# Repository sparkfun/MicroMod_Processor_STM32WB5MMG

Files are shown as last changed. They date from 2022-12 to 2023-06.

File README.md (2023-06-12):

SparkFun MicroMod Processor Board - STM32WB5MMG 
========================================

MicroMod Processor Board - STM32WB5MMG (https://www.sparkfun.com/products/21438)

[*MicroMod Processor Board - STM32WB5MMG (DEV-21438)*](https://www.sparkfun.com/products/21438)

The MicroMod STM32WB5MMG Processor expands on SparkFun&apos;s MicroMod ST product line with a powerful combination of computing and wireless capabilities all on one Processor. The STM32WB5MMG from STMicroelectronics<sup>&trade;</sup> is an ultra-low power microcontroller that combines a pair of Arm<sup>&reg;</sup> Cortex<sup>&reg;</sup> processors; a Cortex-M4 processor for primary computing and a Cortex-M0 to run the 2.4 GHz radio. The radio is Bluetooth<sup>&reg;</sup> Low Energy 5.3, Zigbee<sup>&reg;</sup> 3.0, and OpenThread certified.

Repository Contents
-------------------

* **/Documentation** - Data sheets, additional product information
* **/Firmware** - Example code 
* **/Hardware** - Eagle design files (.brd, .sch)
* **/Production** - Production panel files (.brd)

Documentation
--------------
* **[Hookup Guide](https://learn.sparkfun.com/tutorials/micromod-stm32wb5mmg-hookup-guide)** - Basic hookup guide for the MicroMod Processor Board - STM32WB5MMG .
* **[SparkFun Fritzing repo](https://github.com/sparkfun/Fritzing_Parts)** - Fritzing diagrams for SparkFun products.
* **[SparkFun Graphical Datasheets](https://github.com/sparkfun/Graphical_Datasheets)** -Graphical Datasheets for various SparkFun products.

Product Versions
----------------
* [DEV-21438](https://www.sparkfun.com/products/21438)- MicroMod Processor for the STM32WB5MMG

License Information
-------------------

This product is _**open source**_! 

Please review the LICENSE.md file for license information. 

If you have any questions or concerns on licensing, please contact technical support on our [SparkFun forums](https://forum.sparkfun.com/viewforum.php?f=152).

Distributed as-is; no warranty is given.

- Your friends at SparkFun.

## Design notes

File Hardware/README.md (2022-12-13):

SparkFun <PRODUCT NAME> Design Files
=====================================

The .sch and .brd files hare are Eagle CAD schematic and PCB design files from SparkFun Electronics.
A freeware version of Autodesk Eagle can be found [here](https://www.autodesk.com/products/eagle/free-download).

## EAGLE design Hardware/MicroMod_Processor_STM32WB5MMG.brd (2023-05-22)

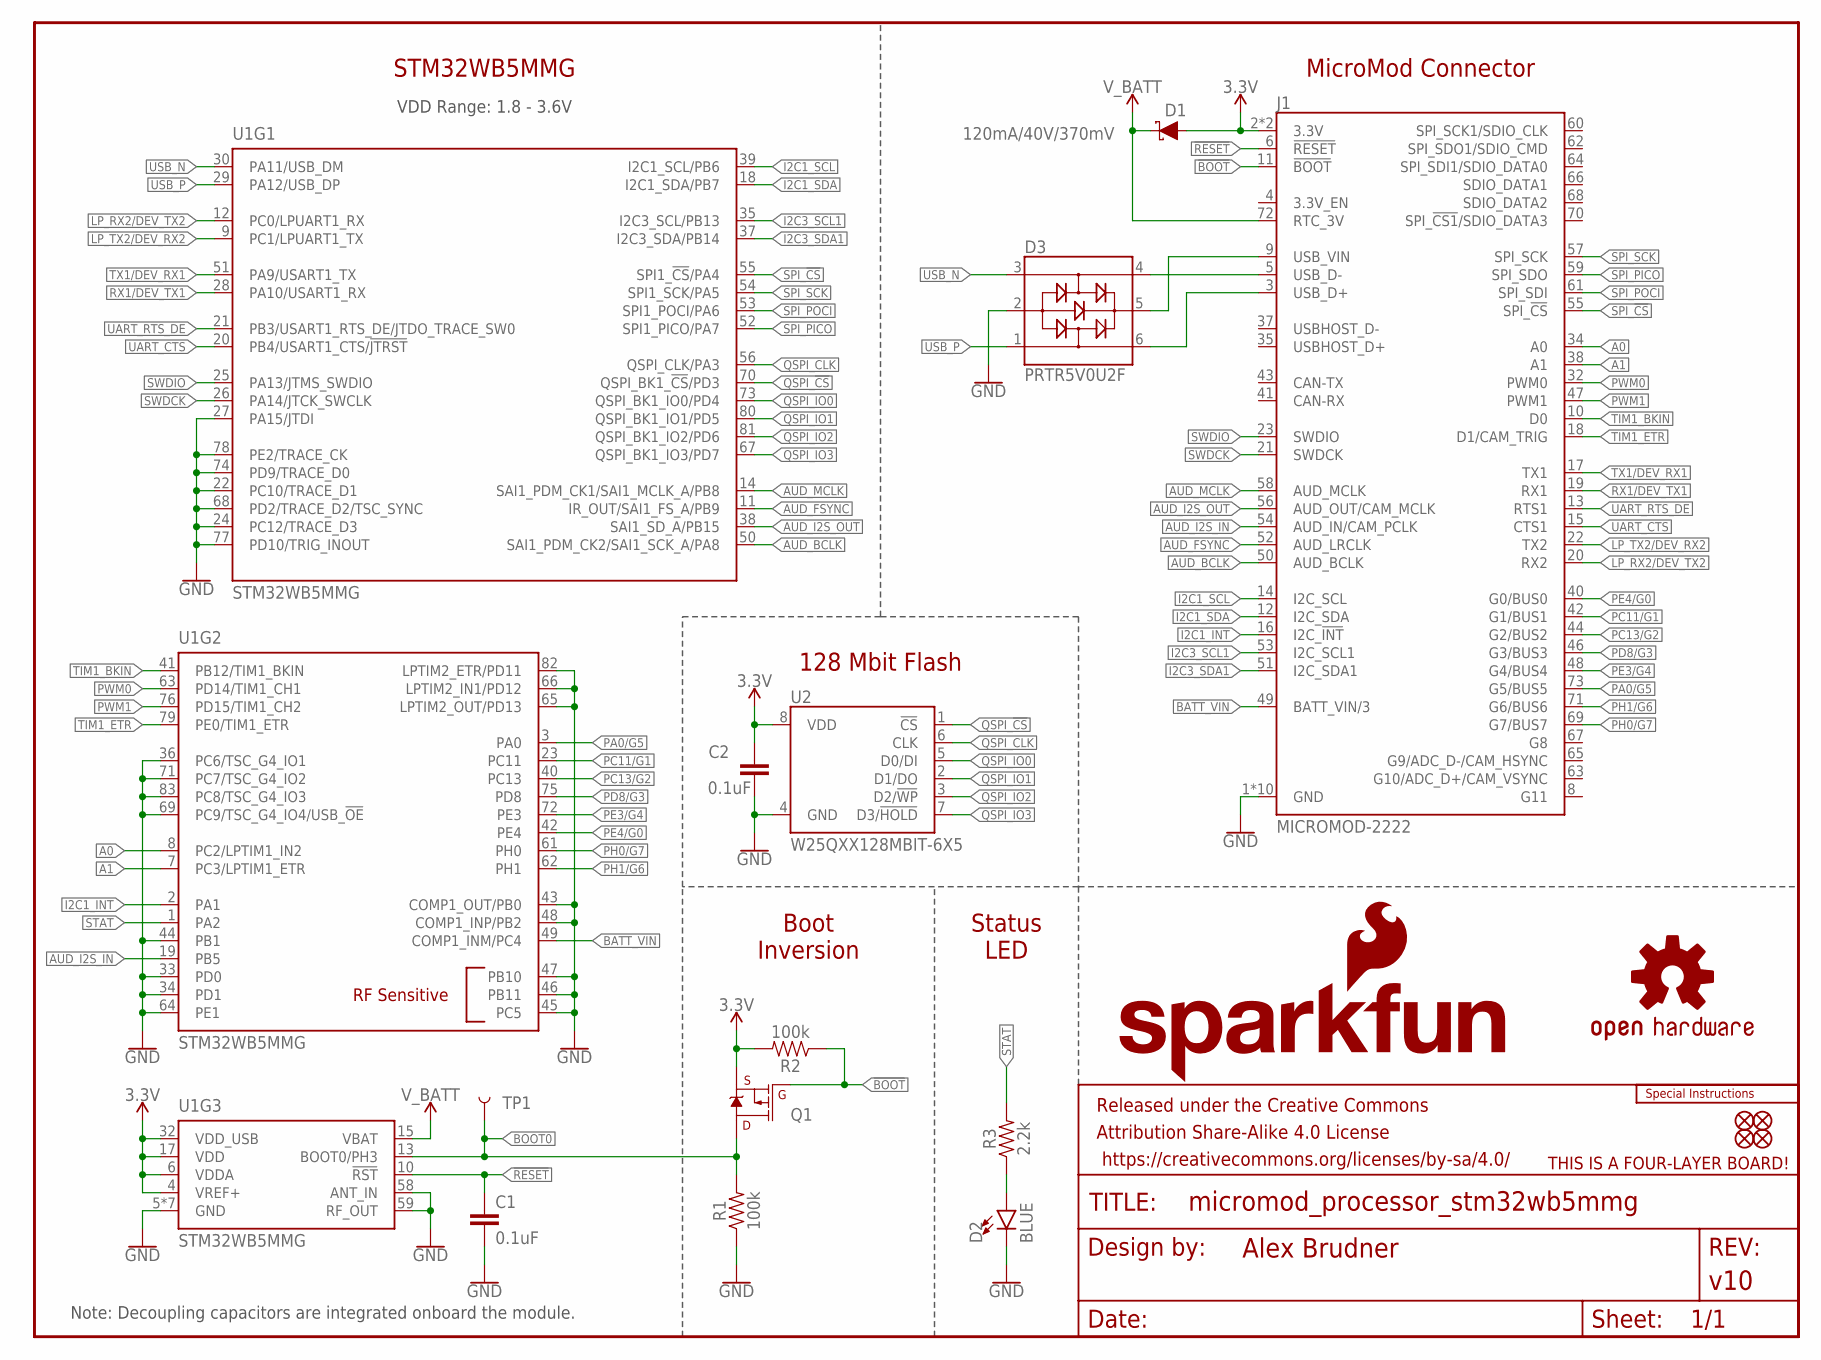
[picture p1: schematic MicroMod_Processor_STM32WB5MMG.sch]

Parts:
C1, C2: 0.1uF; 0402-TIGHT
D1: 120mA/40V/370mV; SOD-523
D2: BLUE; LED-0603
D3: PRTR5V0U2F; SOT886
FD1, FD2, FD3, FD4: FIDUCIALUFIDUCIAL; FIDUCIAL-MICRO
FRAME2: FRAME-LETTER; CREATIVE_COMMONS
J1: MICROMOD-2222; M.2-CARD-E-22
LOGO1: FOUR_LAYER_WARNING
LOGO2: OSHW-LOGOMINI; OSHW-LOGO-MINI
LOGO3: SFE_LOGO_NAME_FLAME.1_INCH; SFE_LOGO_NAME_FLAME_.1
LOGO4: SPECIAL_INSTRUCTIONS-ORDERING; ORDERING_INSTRUCTIONS
Q1: 20V/4.2A/52mΩ/1.4W; SOT23-3
R1, R2: 100k; 0402-TIGHT
R3: 2.2k; 0402-TIGHT
TP1: TEST-POINT3; PAD.03X.03
U1: STM32WB5MMG; SIP-LGA86
U2: W25QXX128MBIT-6X5; WSON-8-6X5

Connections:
3.3V: C2.1, D1.A, J1.2 (3.3V), J1.74 (3.3V), Q1.2 (S), R2.2, U1.4 (VREF+), U1.6 (VDDA), U1.17 (VDD), U1.32 (VDD_USB), U2.8 (VDD)
!BOOT!: J1.11 (!BOOT!), Q1.1 (G), R2.1
!RESET!: C1.1, J1.6 (!RESET!), U1.10 (!RST!)
A0: J1.34 (A0), U1.8 (PC2/LPTIM1_IN2)
A1: J1.38 (A1), U1.7 (PC3/LPTIM1_ETR)
AUD_BCLK: J1.50 (AUD_BCLK), U1.50 (SAI1_PDM_CK2/SAI1_SCK_A/PA8)
AUD_FSYNC: J1.52 (AUD_LRCLK), U1.11 (IR_OUT/SAI1_FS_A/PB9)
AUD_I2S_IN: J1.54 (AUD_IN/CAM_PCLK), U1.19 (PB5)
AUD_I2S_OUT: J1.56 (AUD_OUT/CAM_MCLK), U1.38 (SAI1_SD_A/PB15)
AUD_MCLK: J1.58 (AUD_MCLK), U1.14 (SAI1_PDM_CK1/SAI1_MCLK_A/PB8)
BATT_VIN: J1.49 (BATT_VIN/3), U1.49 (COMP1_INM/PC4)
BOOT0: Q1.3 (D), R1.2, TP1.1, U1.13 (BOOT0/PH3)
GND: C1.2, C2.2, D2.C, D3.2, J1.1 (GND), J1.7 (GND), J1.33 (GND), J1.36 (GND), J1.39 (GND), J1.45 (GND), J1.75 (GND), J1.GND1 (GND), J1.GND2 (GND), J1.GND3 (GND), R1.1, U1.5 (GND), U1.16 (GND), U1.22 (PC10/TRACE_D1), U1.24 (PC12/TRACE_D3), U1.27 (PA15/JTDI), U1.31 (GND), U1.33 (PD0), U1.34 (PD1), U1.36 (PC6/TSC_G4_IO1), U1.43 (COMP1_OUT/PB0), U1.44 (PB1), U1.45 (PC5), U1.46 (PB11), U1.47 (PB10), U1.48 (COMP1_INP/PB2), U1.57 (GND), U1.58 (ANT_IN), U1.59 (RF_OUT), U1.60 (GND), U1.64 (PE1), U1.65 (LPTIM2_OUT/PD13), U1.66 (LPTIM2_IN1/PD12), U1.68 (PD2/TRACE_D2/TSC_SYNC), U1.69 (PC9/TSC_G4_IO4/USB_!OE!), U1.71 (PC7/TSC_G4_IO2), U1.74 (PD9/TRACE_D0), U1.77 (PD10/TRIG_INOUT), U1.78 (PE2/TRACE_CK), U1.82 (LPTIM2_ETR/PD11), U1.83 (PC8/TSC_G4_IO3), U1.84 (GND), U1.86 (GND), U2.4 (GND)
I2C1_INT: J1.16 (I2C_!INT!), U1.2 (PA1)
I2C1_SCL: J1.14 (I2C_SCL), U1.39 (I2C1_SCL/PB6)
I2C1_SDA: J1.12 (I2C_SDA), U1.18 (I2C1_SDA/PB7)
I2C3_SCL1: J1.53 (I2C_SCL1), U1.35 (I2C3_SCL/PB13)
I2C3_SDA1: J1.51 (I2C_SDA1), U1.37 (I2C3_SDA/PB14)
LP_RX2/DEV_TX2: J1.20 (RX2), U1.12 (PC0/LPUART1_RX)
LP_TX2/DEV_RX2: J1.22 (TX2), U1.9 (PC1/LPUART1_TX)
unnamed: D2.A, R3.1
unnamed: D3.5, J1.9 (USB_VIN)
PA0/G5: J1.73 (G5/BUS5), U1.3 (PA0)
PC11/G1: J1.42 (G1/BUS1), U1.23 (PC11)
PC13/G2: J1.44 (G2/BUS2), U1.40 (PC13)
PD8/G3: J1.46 (G3/BUS3), U1.75 (PD8)
PE3/G4: J1.48 (G4/BUS4), U1.72 (PE3)
PE4/G0: J1.40 (G0/BUS0), U1.42 (PE4)
PH0/G7: J1.69 (G7/BUS7), U1.61 (PH0)
PH1/G6: J1.71 (G6/BUS6), U1.62 (PH1)
PWM0: J1.32 (PWM0), U1.63 (PD14/TIM1_CH1)
PWM1: J1.47 (PWM1), U1.76 (PD15/TIM1_CH2)
QSPI_!CS!: U1.70 (QSPI_BK1_!CS!/PD3), U2.1 (!CS!)
QSPI_CLK: U1.56 (QSPI_CLK/PA3), U2.6 (CLK)
QSPI_IO0: U1.73 (QSPI_BK1_IO0/PD4), U2.5 (D0/DI)
QSPI_IO1: U1.80 (QSPI_BK1_IO1/PD5), U2.2 (D1/DO)
QSPI_IO2: U1.81 (QSPI_BK1_IO2/PD6), U2.3 (D2/!WP!)
QSPI_IO3: U1.67 (QSPI_BK1_IO3/PD7), U2.7 (D3/!HOLD!)
RX1/DEV_TX1: J1.19 (RX1), U1.28 (PA10/USART1_RX)
SPI_!CS!: J1.55 (SPI_!CS!), U1.55 (SPI1_!CS!/PA4)
SPI_PICO: J1.59 (SPI_SDO), U1.52 (SPI1_PICO/PA7)
SPI_POCI: J1.61 (SPI_SDI), U1.53 (SPI1_POCI/PA6)
SPI_SCK: J1.57 (SPI_SCK), U1.54 (SPI1_SCK/PA5)
STAT: R3.2, U1.1 (PA2)
SWDCK: J1.21 (SWDCK), U1.26 (PA14/JTCK_SWCLK)
SWDIO: J1.23 (SWDIO), U1.25 (PA13/JTMS_SWDIO)
TIM1_BKIN: J1.10 (D0), U1.41 (PB12/TIM1_BKIN)
TIM1_ETR: J1.18 (D1/CAM_TRIG), U1.79 (PE0/TIM1_ETR)
TX1/DEV_RX1: J1.17 (TX1), U1.51 (PA9/USART1_TX)
UART_CTS: J1.15 (CTS1), U1.20 (PB4/USART1_CTS/!JTRST!)
UART_RTS_DE: J1.13 (RTS1), U1.21 (PB3/USART1_RTS_DE/JTDO_TRACE_SW0)
USBIN_N: D3.4, J1.5 (USB_D-)
USBIN_P: D3.6, J1.3 (USB_D+)
USB_N: D3.3, U1.30 (PA11/USB_DM)
USB_P: D3.1, U1.29 (PA12/USB_DP)
V_BATT: D1.C, J1.72 (RTC_3V), U1.15 (VBAT)

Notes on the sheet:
Note: Decoupling capacitors are integrated onboard the module.
VDD Range: 1.8 - 3.6V
STM32WB5MMG
MicroMod Connector
128 Mbit Flash
Boot Inversion
Status LED

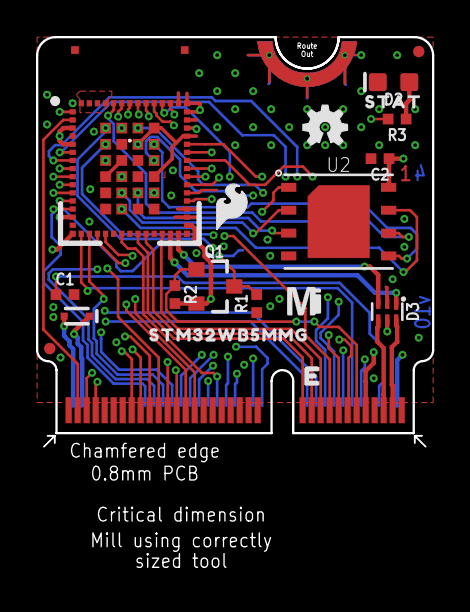
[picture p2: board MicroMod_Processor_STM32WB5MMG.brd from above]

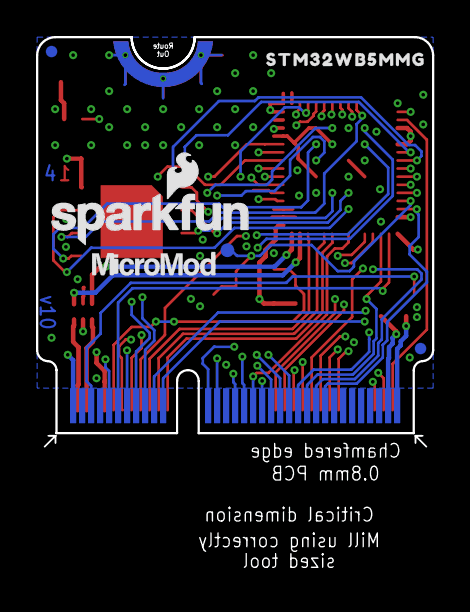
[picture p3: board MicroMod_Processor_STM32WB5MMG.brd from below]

Board: 4 copper layers, 22.0 x 22.8 mm, 29 parts (7 on the bottom side), 56 nets.

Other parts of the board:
U$1: MICROMOD_MI_LOGO_.35
U$2: MICROMOD_LOGO_.3
U$3: SFE_LOGO_FLAME_.1
U$4, U$5: STM32WB5MMG0
U$6: SFE_LOGO_FLAME_STOP_.1
U$7: STAT0

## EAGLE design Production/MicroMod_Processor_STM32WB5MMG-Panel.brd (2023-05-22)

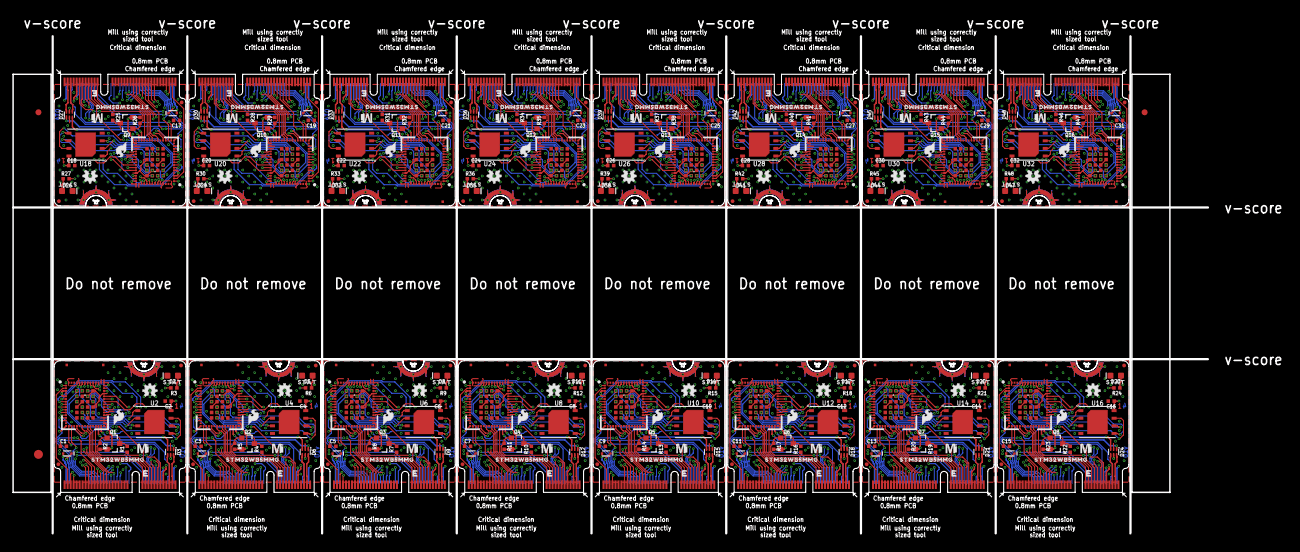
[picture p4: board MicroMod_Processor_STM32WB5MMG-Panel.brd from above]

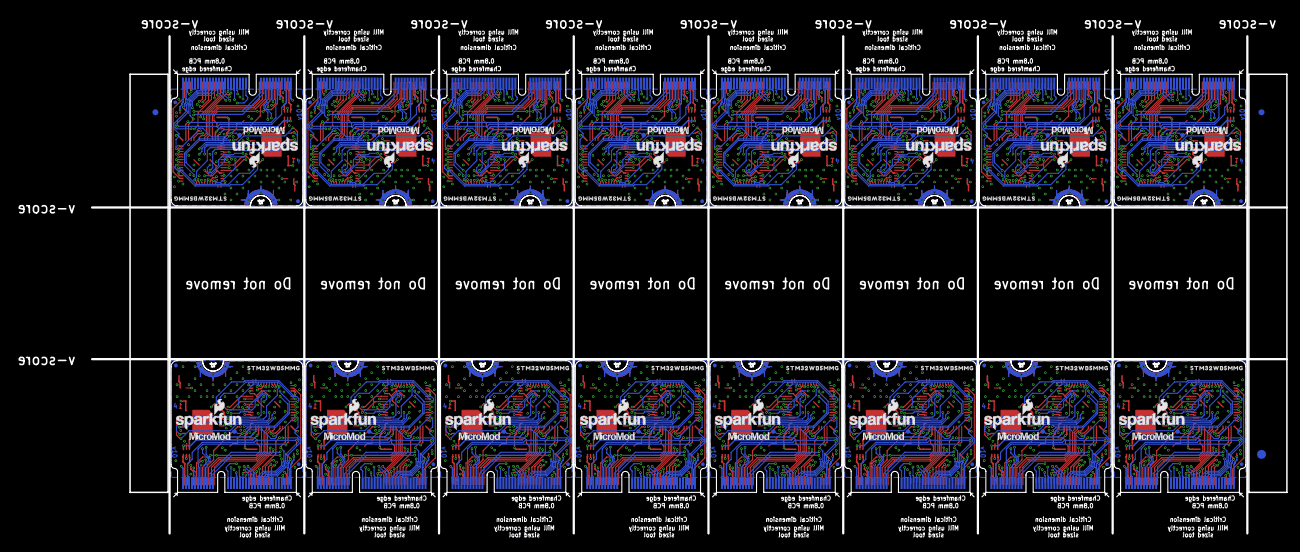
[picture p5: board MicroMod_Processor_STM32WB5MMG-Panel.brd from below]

Board: 4 copper layers, 199.6 x 83.1 mm, 438 parts (115 on the bottom side), 896 nets.

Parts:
C1, C2, C3, C4, C5, C6, C7, C8, C9, C10, C11, C12, C13, C14, C15, C16, C17, C18, C19, C20, C21, C22, C23, C24, C25, C26, C27, C28, C29, C30, C31, C32: 0.1uF; 0402-TIGHT
D1, D4, D7, D10, D13, D16, D19, D22, D25, D28, D31, D34, D37, D40, D43, D46: 120mA/40V/370mV; SOD-523
D2, D5, D8, D11, D14, D17, D20, D23, D26, D29, D32, D35, D38, D41, D44, D47: BLUE; LED-0603
D3, D6, D9, D12, D15, D18, D21, D24, D27, D30, D33, D36, D39, D42, D45, D48: PRTR5V0U2F; SOT886
E$1, E$2, E$3, E$4: FIDUCIAL-1X2
E$5, E$6: FIDUCIAL-1.5X3
FD1, FD2, FD3, FD4, FD5, FD6, FD7, FD8, FD9, FD10, FD11, FD12, FD13, FD14, FD15, FD16, FD17, FD18, FD19, FD20, FD21, FD22, FD23, FD24, FD25, FD26, FD27, FD28, FD29, FD30, FD31, FD32, FD33, FD34, FD35, FD36, FD37, FD38, FD39, FD40, FD41, FD42, FD43, FD44, FD45, FD46, FD47, FD48, FD49, FD50, FD51, FD52, FD53, FD54, FD55, FD56, FD57, FD58, FD59, FD60, FD61, FD62, FD63, FD64: FIDUCIALUFIDUCIAL; FIDUCIAL-MICRO
J1, J2, J3, J4, J5, J6, J7, J8, J9, J10, J11, J12, J13, J14, J15, J16: MICROMOD-2222; M.2-CARD-E-22
LOGO1, LOGO4, LOGO7, LOGO10, LOGO13, LOGO16, LOGO19, LOGO22, LOGO25, LOGO28, LOGO31, LOGO34, LOGO37, LOGO40, LOGO43, LOGO46: FOUR_LAYER_WARNING
LOGO2, LOGO5, LOGO8, LOGO11, LOGO14, LOGO17, LOGO20, LOGO23, LOGO26, LOGO29, LOGO32, LOGO35, LOGO38, LOGO41, LOGO44, LOGO47: OSHW-LOGOMINI; OSHW-LOGO-MINI
LOGO3, LOGO6, LOGO9, LOGO12, LOGO15, LOGO18, LOGO21, LOGO24, LOGO27, LOGO30, LOGO33, LOGO36, LOGO39, LOGO42, LOGO45, LOGO48: SFE_LOGO_NAME_FLAME.1_INCH; SFE_LOGO_NAME_FLAME_.1
Q1, Q2, Q3, Q4, Q5, Q6, Q7, Q8, Q9, Q10, Q11, Q12, Q13, Q14, Q15, Q16: 20V/4.2A/52mΩ/1.4W; SOT23-3
R1, R2, R4, R5, R7, R8, R10, R11, R13, R14, R16, R17, R19, R20, R22, R23, R25, R26, R28, R29, R31, R32, R34, R35, R37, R38, R40, R41, R43, R44, R46, R47: 100k; 0402-TIGHT
R3, R6, R9, R12, R15, R18, R21, R24, R27, R30, R33, R36, R39, R42, R45, R48: 2.2k; 0402-TIGHT
TP1, TP2, TP3, TP4, TP5, TP6, TP7, TP8, TP9, TP10, TP11, TP12, TP13, TP14, TP15, TP16: TEST-POINT3; PAD.03X.03
U1, U3, U5, U7, U9, U11, U13, U15, U17, U19, U21, U23, U25, U27, U29, U31: STM32WB5MMG; SIP-LGA86
U2, U4, U6, U8, U10, U12, U14, U16, U18, U20, U22, U24, U26, U28, U30, U32: W25QXX128MBIT-6X5; WSON-8-6X5
U$1, U$8, U$15, U$22, U$29, U$36, U$43, U$50, U$57, U$64, U$71, U$78, U$85, U$92, U$99, U$106: MICROMOD_MI_LOGO_.35
U$2, U$9, U$16, U$23, U$30, U$37, U$44, U$51, U$58, U$65, U$72, U$79, U$86, U$93, U$100, U$107: MICROMOD_LOGO_.3
U$3, U$10, U$17, U$24, U$31, U$38, U$45, U$52, U$59, U$66, U$73, U$80, U$87, U$94, U$101, U$108: SFE_LOGO_FLAME_.1
U$4, U$5, U$11, U$12, U$18, U$19, U$25, U$26, U$32, U$33, U$39, U$40, U$46, U$47, U$53, U$54, U$60, U$61, U$67, U$68, U$74, U$75, U$81, U$82, U$88, U$89, U$95, U$96, U$102, U$103, U$109, U$110: STM32WB5MMG0
U$6, U$13, U$20, U$27, U$34, U$41, U$48, U$55, U$62, U$69, U$76, U$83, U$90, U$97, U$104, U$111: SFE_LOGO_FLAME_STOP_.1
U$7, U$14, U$21, U$28, U$35, U$42, U$49, U$56, U$63, U$70, U$77, U$84, U$91, U$98, U$105, U$112: STAT0

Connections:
3.3V: C2.1, D1.A, J1.2, J1.74, Q1.2, R2.2, U1.4, U1.6, U1.17, U1.32, U2.8
3.3V1: C4.1, D4.A, J2.2, J2.74, Q2.2, R5.2, U3.4, U3.6, U3.17, U3.32, U4.8
3.3V2: C6.1, D7.A, J3.2, J3.74, Q3.2, R8.2, U5.4, U5.6, U5.17, U5.32, U6.8
3.3V3: C8.1, D10.A, J4.2, J4.74, Q4.2, R11.2, U7.4, U7.6, U7.17, U7.32, U8.8
3.3V4: C10.1, D13.A, J5.2, J5.74, Q5.2, R14.2, U9.4, U9.6, U9.17, U9.32, U10.8
3.3V5: C12.1, D16.A, J6.2, J6.74, Q6.2, R17.2, U11.4, U11.6, U11.17, U11.32, U12.8
3.3V6: C14.1, D19.A, J7.2, J7.74, Q7.2, R20.2, U13.4, U13.6, U13.17, U13.32, U14.8
3.3V7: C16.1, D22.A, J8.2, J8.74, Q8.2, R23.2, U15.4, U15.6, U15.17, U15.32, U16.8
3.3V8: C18.1, D25.A, J9.2, J9.74, Q9.2, R26.2, U17.4, U17.6, U17.17, U17.32, U18.8
3.3V9: C20.1, D28.A, J10.2, J10.74, Q10.2, R29.2, U19.4, U19.6, U19.17, U19.32, U20.8
3.3V10: C22.1, D31.A, J11.2, J11.74, Q11.2, R32.2, U21.4, U21.6, U21.17, U21.32, U22.8
3.3V11: C24.1, D34.A, J12.2, J12.74, Q12.2, R35.2, U23.4, U23.6, U23.17, U23.32, U24.8
3.3V12: C26.1, D37.A, J13.2, J13.74, Q13.2, R38.2, U25.4, U25.6, U25.17, U25.32, U26.8
3.3V13: C28.1, D40.A, J14.2, J14.74, Q14.2, R41.2, U27.4, U27.6, U27.17, U27.32, U28.8
3.3V14: C30.1, D43.A, J15.2, J15.74, Q15.2, R44.2, U29.4, U29.6, U29.17, U29.32, U30.8
3.3V15: C32.1, D46.A, J16.2, J16.74, Q16.2, R47.2, U31.4, U31.6, U31.17, U31.32, U32.8
!BOOT!: J1.11, Q1.1, R2.1
!BOOT!1: J2.11, Q2.1, R5.1
!BOOT!2: J3.11, Q3.1, R8.1
!BOOT!3: J4.11, Q4.1, R11.1
!BOOT!4: J5.11, Q5.1, R14.1
!BOOT!5: J6.11, Q6.1, R17.1
!BOOT!6: J7.11, Q7.1, R20.1
!BOOT!7: J8.11, Q8.1, R23.1
!BOOT!8: J9.11, Q9.1, R26.1
!BOOT!9: J10.11, Q10.1, R29.1
!BOOT!10: J11.11, Q11.1, R32.1
!BOOT!11: J12.11, Q12.1, R35.1
!BOOT!12: J13.11, Q13.1, R38.1
!BOOT!13: J14.11, Q14.1, R41.1
!BOOT!14: J15.11, Q15.1, R44.1
!BOOT!15: J16.11, Q16.1, R47.1
!RESET!: C1.1, J1.6, U1.10
!RESET!1: C3.1, J2.6, U3.10
!RESET!2: C5.1, J3.6, U5.10
!RESET!3: C7.1, J4.6, U7.10
!RESET!4: C9.1, J5.6, U9.10
!RESET!5: C11.1, J6.6, U11.10
!RESET!6: C13.1, J7.6, U13.10
!RESET!7: C15.1, J8.6, U15.10
!RESET!8: C17.1, J9.6, U17.10
!RESET!9: C19.1, J10.6, U19.10
!RESET!10: C21.1, J11.6, U21.10
!RESET!11: C23.1, J12.6, U23.10
!RESET!12: C25.1, J13.6, U25.10
!RESET!13: C27.1, J14.6, U27.10
!RESET!14: C29.1, J15.6, U29.10
!RESET!15: C31.1, J16.6, U31.10
A0: J1.34, U1.8
A1: J1.38, U1.7
A2: J2.34, U3.8
A3: J2.38, U3.7
A4: J3.34, U5.8
A5: J3.38, U5.7
A6: J4.34, U7.8
A7: J4.38, U7.7
A8: J5.34, U9.8
A9: J5.38, U9.7
A10: J6.34, U11.8
A11: J6.38, U11.7
A12: J7.34, U13.8
A13: J7.38, U13.7
A14: J8.34, U15.8
A15: J8.38, U15.7
A16: J9.34, U17.8
A17: J9.38, U17.7
A18: J10.34, U19.8
A19: J10.38, U19.7
A20: J11.34, U21.8
A21: J11.38, U21.7
A22: J12.34, U23.8
A23: J12.38, U23.7
A24: J13.34, U25.8
A25: J13.38, U25.7
A26: J14.34, U27.8
A27: J14.38, U27.7
A28: J15.34, U29.8
A29: J15.38, U29.7
A30: J16.34, U31.8
A31: J16.38, U31.7
AUD_BCLK: J1.50, U1.50
AUD_BCLK1: J2.50, U3.50
AUD_BCLK2: J3.50, U5.50
AUD_BCLK3: J4.50, U7.50
AUD_BCLK4: J5.50, U9.50
AUD_BCLK5: J6.50, U11.50
AUD_BCLK6: J7.50, U13.50
AUD_BCLK7: J8.50, U15.50
AUD_BCLK8: J9.50, U17.50
AUD_BCLK9: J10.50, U19.50
AUD_BCLK10: J11.50, U21.50
AUD_BCLK11: J12.50, U23.50
AUD_BCLK12: J13.50, U25.50
AUD_BCLK13: J14.50, U27.50
AUD_BCLK14: J15.50, U29.50
AUD_BCLK15: J16.50, U31.50
AUD_FSYNC: J1.52, U1.11
AUD_FSYNC1: J2.52, U3.11
AUD_FSYNC2: J3.52, U5.11
AUD_FSYNC3: J4.52, U7.11
AUD_FSYNC4: J5.52, U9.11
AUD_FSYNC5: J6.52, U11.11
AUD_FSYNC6: J7.52, U13.11
AUD_FSYNC7: J8.52, U15.11
AUD_FSYNC8: J9.52, U17.11
AUD_FSYNC9: J10.52, U19.11
AUD_FSYNC10: J11.52, U21.11
AUD_FSYNC11: J12.52, U23.11
AUD_FSYNC12: J13.52, U25.11
AUD_FSYNC13: J14.52, U27.11
AUD_FSYNC14: J15.52, U29.11
AUD_FSYNC15: J16.52, U31.11
AUD_I2S_IN: J1.54, U1.19
AUD_I2S_IN1: J2.54, U3.19
AUD_I2S_IN2: J3.54, U5.19
AUD_I2S_IN3: J4.54, U7.19
AUD_I2S_IN4: J5.54, U9.19
AUD_I2S_IN5: J6.54, U11.19
AUD_I2S_IN6: J7.54, U13.19
AUD_I2S_IN7: J8.54, U15.19
AUD_I2S_IN8: J9.54, U17.19
AUD_I2S_IN9: J10.54, U19.19
AUD_I2S_IN10: J11.54, U21.19
AUD_I2S_IN11: J12.54, U23.19
AUD_I2S_IN12: J13.54, U25.19
AUD_I2S_IN13: J14.54, U27.19
AUD_I2S_IN14: J15.54, U29.19
AUD_I2S_IN15: J16.54, U31.19
AUD_I2S_OUT: J1.56, U1.38
AUD_I2S_OUT1: J2.56, U3.38
AUD_I2S_OUT2: J3.56, U5.38
AUD_I2S_OUT3: J4.56, U7.38
AUD_I2S_OUT4: J5.56, U9.38
AUD_I2S_OUT5: J6.56, U11.38
AUD_I2S_OUT6: J7.56, U13.38
AUD_I2S_OUT7: J8.56, U15.38
AUD_I2S_OUT8: J9.56, U17.38
AUD_I2S_OUT9: J10.56, U19.38
AUD_I2S_OUT10: J11.56, U21.38
AUD_I2S_OUT11: J12.56, U23.38
AUD_I2S_OUT12: J13.56, U25.38
AUD_I2S_OUT13: J14.56, U27.38
AUD_I2S_OUT14: J15.56, U29.38
AUD_I2S_OUT15: J16.56, U31.38
AUD_MCLK: J1.58, U1.14
AUD_MCLK1: J2.58, U3.14
AUD_MCLK2: J3.58, U5.14
AUD_MCLK3: J4.58, U7.14
AUD_MCLK4: J5.58, U9.14
AUD_MCLK5: J6.58, U11.14
AUD_MCLK6: J7.58, U13.14
AUD_MCLK7: J8.58, U15.14
AUD_MCLK8: J9.58, U17.14
AUD_MCLK9: J10.58, U19.14
AUD_MCLK10: J11.58, U21.14
AUD_MCLK11: J12.58, U23.14
AUD_MCLK12: J13.58, U25.14
AUD_MCLK13: J14.58, U27.14
AUD_MCLK14: J15.58, U29.14
AUD_MCLK15: J16.58, U31.14
BATT_VIN: J1.49, U1.49
BATT_VIN1: J2.49, U3.49
BATT_VIN2: J3.49, U5.49
BATT_VIN3: J4.49, U7.49
BATT_VIN4: J5.49, U9.49
BATT_VIN5: J6.49, U11.49
BATT_VIN6: J7.49, U13.49
BATT_VIN7: J8.49, U15.49
BATT_VIN8: J9.49, U17.49
BATT_VIN9: J10.49, U19.49
BATT_VIN10: J11.49, U21.49
BATT_VIN11: J12.49, U23.49
BATT_VIN12: J13.49, U25.49
BATT_VIN13: J14.49, U27.49
BATT_VIN14: J15.49, U29.49
BATT_VIN15: J16.49, U31.49
BOOT0: Q1.3, R1.2, TP1.1, U1.13
BOOT1: Q2.3, R4.2, TP2.1, U3.13
BOOT2: Q3.3, R7.2, TP3.1, U5.13
BOOT3: Q4.3, R10.2, TP4.1, U7.13
BOOT4: Q5.3, R13.2, TP5.1, U9.13
BOOT5: Q6.3, R16.2, TP6.1, U11.13
BOOT6: Q7.3, R19.2, TP7.1, U13.13
BOOT7: Q8.3, R22.2, TP8.1, U15.13
BOOT8: Q9.3, R25.2, TP9.1, U17.13
BOOT9: Q10.3, R28.2, TP10.1, U19.13
BOOT10: Q11.3, R31.2, TP11.1, U21.13
BOOT11: Q12.3, R34.2, TP12.1, U23.13
BOOT12: Q13.3, R37.2, TP13.1, U25.13
BOOT13: Q14.3, R40.2, TP14.1, U27.13
BOOT14: Q15.3, R43.2, TP15.1, U29.13
BOOT15: Q16.3, R46.2, TP16.1, U31.13
GND: C1.2, C2.2, D2.C, D3.2, J1.1, J1.7, J1.33, J1.36, J1.39, J1.45, J1.75, J1.GND1, J1.GND2, J1.GND3, R1.1, U1.5, U1.16, U1.22, U1.24, U1.27, U1.31, U1.33, U1.34, U1.36, U1.43, U1.44, U1.45, U1.46, U1.47, U1.48, U1.57, U1.58, U1.59, U1.60, U1.64, U1.65, U1.66, U1.68, U1.69, U1.71, U1.74, U1.77, U1.78, U1.82, U1.83, U1.84, U1.86, U2.4
GND2: C3.2, C4.2, D5.C, D6.2, J2.1, J2.7, J2.33, J2.36, J2.39, J2.45, J2.75, J2.GND1, J2.GND2, J2.GND3, R4.1, U3.5, U3.16, U3.22, U3.24, U3.27, U3.31, U3.33, U3.34, U3.36, U3.43, U3.44, U3.45, U3.46, U3.47, U3.48, U3.57, U3.58, U3.59, U3.60, U3.64, U3.65, U3.66, U3.68, U3.69, U3.71, U3.74, U3.77, U3.78, U3.82, U3.83, U3.84, U3.86, U4.4
GND4: C5.2, C6.2, D8.C, D9.2, J3.1, J3.7, J3.33, J3.36, J3.39, J3.45, J3.75, J3.GND1, J3.GND2, J3.GND3, R7.1, U5.5, U5.16, U5.22, U5.24, U5.27, U5.31, U5.33, U5.34, U5.36, U5.43, U5.44, U5.45, U5.46, U5.47, U5.48, U5.57, U5.58, U5.59, U5.60, U5.64, U5.65, U5.66, U5.68, U5.69, U5.71, U5.74, U5.77, U5.78, U5.82, U5.83, U5.84, U5.86, U6.4
GND6: C7.2, C8.2, D11.C, D12.2, J4.1, J4.7, J4.33, J4.36, J4.39, J4.45, J4.75, J4.GND1, J4.GND2, J4.GND3, R10.1, U7.5, U7.16, U7.22, U7.24, U7.27, U7.31, U7.33, U7.34, U7.36, U7.43, U7.44, U7.45, U7.46, U7.47, U7.48, U7.57, U7.58, U7.59, U7.60, U7.64, U7.65, U7.66, U7.68, U7.69, U7.71, U7.74, U7.77, U7.78, U7.82, U7.83, U7.84, U7.86, U8.4
GND8: C9.2, C10.2, D14.C, D15.2, J5.1, J5.7, J5.33, J5.36, J5.39, J5.45, J5.75, J5.GND1, J5.GND2, J5.GND3, R13.1, U9.5, U9.16, U9.22, U9.24, U9.27, U9.31, U9.33, U9.34, U9.36, U9.43, U9.44, U9.45, U9.46, U9.47, U9.48, U9.57, U9.58, U9.59, U9.60, U9.64, U9.65, U9.66, U9.68, U9.69, U9.71, U9.74, U9.77, U9.78, U9.82, U9.83, U9.84, U9.86, U10.4
GND10: C11.2, C12.2, D17.C, D18.2, J6.1, J6.7, J6.33, J6.36, J6.39, J6.45, J6.75, J6.GND1, J6.GND2, J6.GND3, R16.1, U11.5, U11.16, U11.22, U11.24, U11.27, U11.31, U11.33, U11.34, U11.36, U11.43, U11.44, U11.45, U11.46, U11.47, U11.48, U11.57, U11.58, U11.59, U11.60, U11.64, U11.65, U11.66, U11.68, U11.69, U11.71, U11.74, U11.77, U11.78, U11.82, U11.83, U11.84, U11.86, U12.4
GND12: C13.2, C14.2, D20.C, D21.2, J7.1, J7.7, J7.33, J7.36, J7.39, J7.45, J7.75, J7.GND1, J7.GND2, J7.GND3, R19.1, U13.5, U13.16, U13.22, U13.24, U13.27, U13.31, U13.33, U13.34, U13.36, U13.43, U13.44, U13.45, U13.46, U13.47, U13.48, U13.57, U13.58, U13.59, U13.60, U13.64, U13.65, U13.66, U13.68, U13.69, U13.71, U13.74, U13.77, U13.78, U13.82, U13.83, U13.84, U13.86, U14.4
GND14: C15.2, C16.2, D23.C, D24.2, J8.1, J8.7, J8.33, J8.36, J8.39, J8.45, J8.75, J8.GND1, J8.GND2, J8.GND3, R22.1, U15.5, U15.16, U15.22, U15.24, U15.27, U15.31, U15.33, U15.34, U15.36, U15.43, U15.44, U15.45, U15.46, U15.47, U15.48, U15.57, U15.58, U15.59, U15.60, U15.64, U15.65, U15.66, U15.68, U15.69, U15.71, U15.74, U15.77, U15.78, U15.82, U15.83, U15.84, U15.86, U16.4
GND16: C17.2, C18.2, D26.C, D27.2, J9.1, J9.7, J9.33, J9.36, J9.39, J9.45, J9.75, J9.GND1, J9.GND2, J9.GND3, R25.1, U17.5, U17.16, U17.22, U17.24, U17.27, U17.31, U17.33, U17.34, U17.36, U17.43, U17.44, U17.45, U17.46, U17.47, U17.48, U17.57, U17.58, U17.59, U17.60, U17.64, U17.65, U17.66, U17.68, U17.69, U17.71, U17.74, U17.77, U17.78, U17.82, U17.83, U17.84, U17.86, U18.4
GND18: C19.2, C20.2, D29.C, D30.2, J10.1, J10.7, J10.33, J10.36, J10.39, J10.45, J10.75, J10.GND1, J10.GND2, J10.GND3, R28.1, U19.5, U19.16, U19.22, U19.24, U19.27, U19.31, U19.33, U19.34, U19.36, U19.43, U19.44, U19.45, U19.46, U19.47, U19.48, U19.57, U19.58, U19.59, U19.60, U19.64, U19.65, U19.66, U19.68, U19.69, U19.71, U19.74, U19.77, U19.78, U19.82, U19.83, U19.84, U19.86, U20.4
GND20: C21.2, C22.2, D32.C, D33.2, J11.1, J11.7, J11.33, J11.36, J11.39, J11.45, J11.75, J11.GND1, J11.GND2, J11.GND3, R31.1, U21.5, U21.16, U21.22, U21.24, U21.27, U21.31, U21.33, U21.34, U21.36, U21.43, U21.44, U21.45, U21.46, U21.47, U21.48, U21.57, U21.58, U21.59, U21.60, U21.64, U21.65, U21.66, U21.68, U21.69, U21.71, U21.74, U21.77, U21.78, U21.82, U21.83, U21.84, U21.86, U22.4
GND22: C23.2, C24.2, D35.C, D36.2, J12.1, J12.7, J12.33, J12.36, J12.39, J12.45, J12.75, J12.GND1, J12.GND2, J12.GND3, R34.1, U23.5, U23.16, U23.22, U23.24, U23.27, U23.31, U23.33, U23.34, U23.36, U23.43, U23.44, U23.45, U23.46, U23.47, U23.48, U23.57, U23.58, U23.59, U23.60, U23.64, U23.65, U23.66, U23.68, U23.69, U23.71, U23.74, U23.77, U23.78, U23.82, U23.83, U23.84, U23.86, U24.4
GND24: C25.2, C26.2, D38.C, D39.2, J13.1, J13.7, J13.33, J13.36, J13.39, J13.45, J13.75, J13.GND1, J13.GND2, J13.GND3, R37.1, U25.5, U25.16, U25.22, U25.24, U25.27, U25.31, U25.33, U25.34, U25.36, U25.43, U25.44, U25.45, U25.46, U25.47, U25.48, U25.57, U25.58, U25.59, U25.60, U25.64, U25.65, U25.66, U25.68, U25.69, U25.71, U25.74, U25.77, U25.78, U25.82, U25.83, U25.84, U25.86, U26.4
GND26: C27.2, C28.2, D41.C, D42.2, J14.1, J14.7, J14.33, J14.36, J14.39, J14.45, J14.75, J14.GND1, J14.GND2, J14.GND3, R40.1, U27.5, U27.16, U27.22, U27.24, U27.27, U27.31, U27.33, U27.34, U27.36, U27.43, U27.44, U27.45, U27.46, U27.47, U27.48, U27.57, U27.58, U27.59, U27.60, U27.64, U27.65, U27.66, U27.68, U27.69, U27.71, U27.74, U27.77, U27.78, U27.82, U27.83, U27.84, U27.86, U28.4
GND28: C29.2, C30.2, D44.C, D45.2, J15.1, J15.7, J15.33, J15.36, J15.39, J15.45, J15.75, J15.GND1, J15.GND2, J15.GND3, R43.1, U29.5, U29.16, U29.22, U29.24, U29.27, U29.31, U29.33, U29.34, U29.36, U29.43, U29.44, U29.45, U29.46, U29.47, U29.48, U29.57, U29.58, U29.59, U29.60, U29.64, U29.65, U29.66, U29.68, U29.69, U29.71, U29.74, U29.77, U29.78, U29.82, U29.83, U29.84, U29.86, U30.4
GND30: C31.2, C32.2, D47.C, D48.2, J16.1, J16.7, J16.33, J16.36, J16.39, J16.45, J16.75, J16.GND1, J16.GND2, J16.GND3, R46.1, U31.5, U31.16, U31.22, U31.24, U31.27, U31.31, U31.33, U31.34, U31.36, U31.43, U31.44, U31.45, U31.46, U31.47, U31.48, U31.57, U31.58, U31.59, U31.60, U31.64, U31.65, U31.66, U31.68, U31.69, U31.71, U31.74, U31.77, U31.78, U31.82, U31.83, U31.84, U31.86, U32.4
I2C1_INT: J1.16, U1.2
I2C1_INT1: J2.16, U3.2
I2C1_INT2: J3.16, U5.2
I2C1_INT3: J4.16, U7.2
I2C1_INT4: J5.16, U9.2
I2C1_INT5: J6.16, U11.2
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

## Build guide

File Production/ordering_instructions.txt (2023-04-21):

panel size, 194x70mm
PCB thickness, 0.8mm
number of layers, 4
controlled impedance, JLC7628
bevel, Gold Fingers + 45° Finger Chamfered
material, TG155
soldermask color, Red
silkscreen color, White
oz copper, 1oz
finish, ENIG
stencils, top
pcs per panel, 16
min trace width, 0.1500mm / 0.0059in
min drill size, 0.2000mm / 0.0079in
filename to layer stackup 1/2/3/4: GTL, GL2, GL3, GBL

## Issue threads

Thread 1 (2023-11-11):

Cannot get basic examples working on the Asset Tracker board using the STM32WB5MMG processor.

peekd, 2023-11-11:
Trying to get AssetTracker_Example1_Blink going but can't even compile (see errors below).

From another user - dboddie - 👍

In file included from D:\code\Asset_Tracker\MicroMod_Asset_Tracker-main\Examples\AssetTracker_Example1_Blink\AssetTracker_Example1_Blink.ino:39:
D:\code\Asset_Tracker\MicroMod_Asset_Tracker-main\Examples\AssetTracker_Example1_Blink\AssetTrackerPins.h:90:24: error: 'RX1' was not declared in this scope
90 | HardwareSerial Serial1(RX1, TX1);
| ^~~
D:\code\Asset_Tracker\MicroMod_Asset_Tracker-main\Examples\AssetTracker_Example1_Blink\AssetTrackerPins.h:90:29: error: 'TX1' was not declared in this scope
90 | HardwareSerial Serial1(RX1, TX1);
| ^~~
D:\code\Asset_Tracker\MicroMod_Asset_Tracker-main\Examples\AssetTracker_Example1_Blink\AssetTrackerPins.h:105:28: error: 'G0' was not declared in this scope; did you mean 'y0'?
105 | const int MICROSD_CS = G0; // Output: Active low
| ^~
| y0
D:\code\Asset_Tracker\MicroMod_Asset_Tracker-main\Examples\AssetTracker_Example1_Blink\AssetTrackerPins.h:106:28: error: 'G1' was not declared in this scope; did you mean 'y1'?
106 | const int MICROSD_PWR_EN = G1; // Output: Pull low to enable power for the SD card. Pull high to disable.
| ^~
| y1
D:\code\Asset_Tracker\MicroMod_Asset_Tracker-main\Examples\AssetTracker_Example1_Blink\AssetTrackerPins.h:107:28: error: 'G2' was not declared in this scope; did you mean 'D2'?
107 | const int SARA_PWR = G2; // Output: Pull high then low to switch the SARA-R5 on. Pull high for five seconds then low again to switch it off.
| ^~
| D2
D:\code\Asset_Tracker\MicroMod_Asset_Tracker-main\Examples\AssetTracker_Example1_Blink\AssetTrackerPins.h:108:28: error: 'G3' was not declared in this scope; did you mean 'D3'?
108 | const int IMU_PWR_EN = G3; // Output: Pull high to enable power for the IMU. Pull low to disable.
| ^~
| D3
D:\code\Asset_Tracker\MicroMod_Asset_Tracker-main\Examples\AssetTracker_Example1_Blink\AssetTrackerPins.h:109:28: error: 'G4' was not declared in this scope; did you mean 'D4'?
109 | const int SARA_RI = G4; // Input: SARA-R5 Ring Indicator pin. Becomes CTS2 in 2-UART mode.
| ^~
| D4
D:\code\Asset_Tracker\MicroMod_Asset_Tracker-main\Examples\AssetTracker_Example1_Blink\AssetTrackerPins.h:110:28: error: 'G5' was not declared in this scope; did you mean 'D5'?
110 | const int SARA_INT = G5; // Input: SARA-R5 EXT_INT interrupt pin.
| ^~
| D5
D:\code\Asset_Tracker\MicroMod_Asset_Tracker-main\Examples\AssetTracker_Example1_Blink\AssetTrackerPins.h:111:28: error: 'G6' was not declared in this scope; did you mean 'D6'?
111 | const int SARA_ON = G6; // Input: Pulled low when the SARA-R5 is on. Pulled high when the SARA-R5 is off.
| ^~
| D6
D:\code\Asset_Tracker\MicroMod_Asset_Tracker-main\Examples\AssetTracker_Example1_Blink\AssetTrackerPins.h:87:16: error: 'INT' was not declared in this scope; did you mean 'IN'?
87 | #define I2CINT INT
| ^~~
D:\code\Asset_Tracker\MicroMod_Asset_Tracker-main\Examples\AssetTracker_Example1_Blink\AssetTrackerPins.h:121:21: note: in expansion of macro 'I2CINT'
121 | const int IMU_INT = I2CINT; // Input: IMU interrupt pin
| ^~~~~~

exit status 1

Compilation error: 'RX1' was not declared in this scope

SFE-Brudnerd, 2023-11-15:
Hi @peekd, I've got this on my to-do list, but I probably won't be able to get to it for a couple weeks due to higher priority work. In the meantime, please feel free to submit a pull request in the `Arduino_Core_STM32` repo and add me as a reviewer. It would be an easy first PR for you. Please note that whether I do it or you do it, you won't see the change in Arduino immediately as they only update for tags. In the meantime, you can clone the `Arduino_Core_STM32` repo to your `$Arduino\hardware` folder, and after restarting Arduino it should show up as `STM32 MCU based boards (in Sketchbook)` in your boards drop-down list and you can pick the board from there. Thanks!

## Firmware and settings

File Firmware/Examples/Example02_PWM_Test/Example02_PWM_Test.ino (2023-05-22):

/**
 * @file Example02_PWM_Test.ino
 * @brief This example sets the PWM channels to be read by an oscilloscope.
 * @copyright SPDX-License-Identifier: MIT
 * @author Alex Brudner, SparkFun Electronics
 * @date 2023-04-18
 * @note Based on the PWM example from ST here:
 * https://github.com/stm32duino/STM32Examples
 *
 * Feel like supporting open source hardware?
 * Buy a board from SparkFun!
 *      MicroMod STM32WB5MMG Processor Board
 *        | https://www.sparkfun.com/products/21438
 *      MicroMod ATP Carrier Board                       
 *        | https://www.sparkfun.com/products/16885
 */

#include <Arduino.h>

#define PWM0 PD14
#define PWM1 PD15
// #define EX_TRIG PE0
// #define PWM_BRK PB12

void setup() {
  // put your setup code here, to run once:
  Serial.begin(115200);
  while(!Serial) { delay(100); };

  Serial.println(F("Begin PWM Test."));


  TIM_TypeDef *tim_pwm0 = (TIM_TypeDef *)pinmap_peripheral(digitalPinToPinName(PWM0), PinMap_PWM);
  uint32_t channel_pwm0 = STM_PIN_CHANNEL(pinmap_function(digitalPinToPinName(PWM0), PinMap_PWM));
  
  HardwareTimer *MyTim_pwm0 = new HardwareTimer(tim_pwm0);
  MyTim_pwm0->setPWM(channel_pwm0, PWM0, 50000, 25);

  TIM_TypeDef *tim_pwm1 = (TIM_TypeDef *)pinmap_peripheral(digitalPinToPinName(PWM1), PinMap_PWM);
  uint32_t channel_pwm1 = STM_PIN_CHANNEL(pinmap_function(digitalPinToPinName(PWM1), PinMap_PWM));

  
  HardwareTimer *MyTim_pwm1 = new HardwareTimer(tim_pwm1);
  MyTim_pwm1->setPWM(channel_pwm1, PWM1, 50000, 75);  
}

void loop() {

}

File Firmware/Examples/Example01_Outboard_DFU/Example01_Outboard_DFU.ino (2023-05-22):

/**
 * @file Example01_Outboard_DFU.ino
 * @brief This example performs an Outboard Device Firmware Update.
 * @copyright SPDX-License-Identifier: MIT
 * @author Alex Brudner, SparkFun Electronics
 * @date 2023-04-13
 * @note Based on the DFU example from Blues Wireless. See
 * https://github.com/blues/note-outboard-dfu
 * 
 * ========== HARDWARE CONNECTIONS ==========
 * MicroMod STM32WB5MMG Processor Board => MicroMod Main Board => MicroMod 
 *  Function Board Blues Wireless Notecarrier
 *
 * Feel like supporting open source hardware?
 * Buy a board from SparkFun!
 *      MicroMod Function Board Blues Wireless Notecarrier  
 *        | https://www.sparkfun.com/products/20409
 *      MicroMod STM32WB5MMG Processor Board
 *        | https://www.sparkfun.com/products/21438
 *      MicroMod Main Board - Double                        
 *        | https://www.sparkfun.com/products/18575
 */

#include <Arduino.h>
#include <Notecard.h>

#define PRODUCT_UID "com.your-company.your-name:your_product"

int ledPin = LED_BUILTIN;

Notecard notecard;

void setup()
{
    pinMode(ledPin, OUTPUT);
    
    /* Begin Serial communications */
    Serial.begin(115200);
    Serial.println(F("Begin - STM32WB5MMG MicroMod Notecarrier Example 01: Outboard DFU"));
    notecard.setDebugOutputStream(Serial);

    /* Begin Serial communications */
    Wire.begin();
    notecard.begin();

    /* Configure Notecard */
    J *req = notecard.newRequest("hub.set");
    JAddStringToObject(req, "product", PRODUCT_UID);
    JAddStringToObject(req, "mode", "continuous");
    JAddStringToObject(req, "sn", "stm32wb5mmg-micromod-v01-SN0001");
    notecard.sendRequest(req);

    /* Configure DFU settings */
    req = notecard.newRequest("card.dfu");
    JAddStringToObject(req, "name", "stm32-bi"); /* bi == boot inversion */
    JAddBoolToObject(req, "on", true);
    notecard.sendRequest(req);
}

void loop()
{
    /* Fast Blink LED while waiting for DFU. */
    Serial.println("Hello, world!");
    digitalWrite(ledPin, HIGH);
    delay(100);
    digitalWrite(ledPin, LOW);
    delay(400);
}

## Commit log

2022-12-14 Added schematic/board/initial library.
    [MicroMod_Processor_STM32WB5MMG.brd, MicroMod_Processor_STM32WB5MMG.sch]
2023-01-09 Nearing layout completion.
    [MicroMod_Processor_STM32WB5MMG.brd, MicroMod_Processor_STM32WB5MMG.sch]
2023-01-10 Layout complete.
    [MicroMod_Processor_STM32WB5MMG.brd, MicroMod_Processor_STM32WB5MMG.sch]
2023-01-10 Last update for protos.
    [MicroMod_Processor_STM32WB5MMG.brd, MicroMod_Processor_STM32WB5MMG.sch]
2023-01-17 Updates from Design Review v01
    Fix footprint.
    Reposition bottom silk
    Removed extraneous vias.
    Renamed some nets to match micromod connector.
    Rerouted some traces.
    Added ground vias near fast switching vias.
    Moved traces to expand ground plane.
    Removed all but BOOT0 test point with Chris' approval.
    [MicroMod_Processor_STM32WB5MMG.brd, MicroMod_Processor_STM32WB5MMG.sch]
2023-01-17 Protos commit
    Schematic - Revector all fonts
    Board - Straighten one trace.
    Panel - Panelize and CAM.
    [MicroMod_Processor_STM32WB5MMG-Panel.GBL, MicroMod_Processor_STM32WB5MMG-Panel.GBO, MicroMod_Processor_STM32WB5MMG-Panel.GBP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]
2023-02-15 Move Gerbers to Production folder
    [MicroMod_Processor_STM32WB5MMG-Panel.GBL, MicroMod_Processor_STM32WB5MMG-Panel.GBO, MicroMod_Processor_STM32WB5MMG-Panel.GBP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]
2023-04-21 Update for v10
    Changelog from v01:
    * Connect unused GPIO to ground
    ** AN4899
    ** Reduces power consumption and noise
    * Add ESD to USB data lines
    ** This module is sensitive to it
    ** Moved Flash chip up to make room for ESD diode package
    * Set text objects to spin
    ** When panelizing, the upside down ones didn’t spin on protos so I fixed that
    [MicroMod_Processor_STM32WB5MMG-Panel.GBL, MicroMod_Processor_STM32WB5MMG-Panel.GBO, MicroMod_Processor_STM32WB5MMG-Panel.GBS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]
2023-05-22 v10 Update
    [MicroMod_Processor_STM32WB5MMG-Panel.GBL, MicroMod_Processor_STM32WB5MMG-Panel.GBO, MicroMod_Processor_STM32WB5MMG-Panel.GBS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]

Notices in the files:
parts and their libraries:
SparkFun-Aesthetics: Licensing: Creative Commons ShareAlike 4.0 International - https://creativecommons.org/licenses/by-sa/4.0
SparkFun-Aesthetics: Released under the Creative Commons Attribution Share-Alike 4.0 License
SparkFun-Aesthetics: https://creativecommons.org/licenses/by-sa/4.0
